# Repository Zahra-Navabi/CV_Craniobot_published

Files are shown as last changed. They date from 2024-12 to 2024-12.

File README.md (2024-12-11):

# CV-Craniobot

## Preprint
You can find the preprint of this work at:  
[https://www.biorxiv.org/content/10.1101/2024.09.03.611036v1](https://www.biorxiv.org/content/10.1101/2024.09.03.611036v1)

## Repository Structure
- **Robot_files**: Contains all robot software files.
- **CAD_files**: Contains all CAD files of the robot parts.
- **Other_files**: Other related files.

## Requirements
In addition to MATLAB and LabVIEW, the following software must be installed:  
- **Kinesis software** from Thorlabs  
  [Kinesis-LabVIEW Documentation](https://www.thorlabs.com/Software/Motion%20Control/Kinesis/Kinesis-labview.pdf)  
- **OCT system native software** (Lumedica OQ Stratoscope)  
- **Virtual Serial Port Driver**

## Usage
Ensure all dependencies are installed before running the software. Follow the provided documentation for setup and usage instructions.

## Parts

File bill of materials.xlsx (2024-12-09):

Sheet: Purchased equipments
OCT equipment | Part number | Count | Price for each | Link | Cost
OQ Stratascope 1.0 |  | 1 | 19995.00 | https://www.lumedicasystems.com/stratascope/ | 19995
Extended support for OQ Stratascope |  | 1 | 1895.00 |  | 1895
Workstation Package for OQ Stratascope |  | 1 | 595.00 |  | 595
Virtual Serial Port Virtual serial port |  | 1 | 295.00 |  | 295
Optomechanical parts (purchased)
Aluminum Breadboard 12" x 24" x 1/2", 1/4"-20 Taps | MB1224 | 1 | 302.56 | https://www.thorlabs.com/thorproduct.cfm?partnumber=MB1224 | 302.56
Right-Angle Mounting Plate, 1/4"-20 Compatible | AP90 | 2 | 94.74 | https://www.thorlabs.com/thorproduct.cfm?partnumber=AP90#ad-image-0 | 189.48
4-40 Stainless Steel Cap Screw, 3/8" Long, 50 Pack | SH4S038 | 1 | 9.5 | https://www.thorlabs.com/thorproduct.cfm?partnumber=SH4S038 | 9.5
Low-Profile T-Nut, 1/4"-20 Tapped Hole, 10 Pack | XE25T3 | 1 | 11.65 | https://www.thorlabs.com/thorproduct.cfm?partnumber=XE25T3 | 11.65
30°/60° Angled Mounting Plate, 1/4"-20 Compatible | AP30 | 1 | 147.91 | https://www.thorlabs.com/thorproduct.cfm?partnumber=AP30 | 147.91
50 mm x 75 mm Construction Rail, 20" Long, 1/4"-20 Taps | XE5075L20 | 2 | 89.28 | https://www.thorlabs.com/thorproduct.cfm?partnumber=XE5075L20 | 178.56
Right-Angle Clamp for Ø1/2" Posts, 3/16" Hex | RA90 | 3 | 10.82 | https://www.thorlabs.com/thorproduct.cfm?partnumber=RA90 | 32.46
Adapter Plate with 1/4"-20 and 8-32 Tapped Holes for MTS25 and MTS50 Stages | MTSA1 | 2 | 51.98 | https://www.thorlabs.com/thorproduct.cfm?partnumber=MTSA1 | 103.96
Ø1/2" Optical Post, SS, 8-32 Setscrew, 1/4"-20 Tap, L = 2" | TR2 | 6 | 5.9 | https://www.thorlabs.com/thorproduct.cfm?partnumber=TR2 | 35.4
3" Long Corner Bracket for Aluminum Bolt-Together Framing | 8681N11 | 8 | 13.96 | https://www.mcmaster.com/products/l-shaped-brackets/aluminum-bolt-together-framing-and-fittings/ | 111.68
Load-Rated Threaded Bumper | 93115K111 | 6 | 3 | https://www.mcmaster.com/93115K111/ | 18
motorized stages
50 mm (1.97") Motorized Translation Stage Bundled with Controller and Power Supply, 8-32 and 4-40 Taps | KMTS50E | 2 | 1856.26 | https://www.thorlabs.com/thorproduct.cfm?partnumber=KMTS50E#ad-image-0 | 3712.52
300 mm Translation Stage with Stepper Motor, Integrated Controller, M6 Taps | LTS300C | 1 | 3595.86 | https://www.thorlabs.com/thorproduct.cfm?partnumber=LTS300C | 3595.86
30 mm Motorized Linear Translation Stage, 1/4"-20 Tapped Holes | M30X - Kinesis | 1 | 2920.09 | https://www.thorlabs.com/thorproduct.cfm?partnumber=M30X | 2920.09
Other equipments: |  |  |  |  | 0
AMD Ryzen Series Video Editing Custom PC System * |  | 1 | 3023.83 |  | 3023.83
Miniature End Mills - Square - Stub & Standard, Miniature End Mills | 13908 | 1 | 35.2 | https://www.harveytool.com/products/tool-details-13908 | 35.2
Rampower Digital 45 Sets | RAMPOWER45SETC2 | 1 | 285 | https://www.ramprodinc.com/rampower-digital-45-sets/ | 285
MS100 Portable USB Microscope | TSMS100 | 1 | 39.99 | https://teslong.com/products/ms100-industrial | 39.99
Surge Protector Power Strip |  | 1 | 15.99 | https://www.amazon.com/Protector-Nuetsa-Extension-Outlets-Joules/dp/B09F2XPJ47?hvadid=697649766938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 | 15.99
Powered USB 3.0 Hub, Wenter 11-Port Hub Splitter |  | 1 | 38.99 | https://www.amazon.com/WENTER-Splitter-Individual-Switches-Charging/dp/B08YNPXPRW | 38.99
* Specs: AMD Ryzen Series Video Editing Custom PC System Computer Case: Corsair Carbide Series 4000D Black ATX Case Fan: 120mm Ball Bearing Case Fan Power Supply: Thermaltake Smart 600W 80 PLUS Bronze Power Supply Motherboard: GIGABYTE X570 AORUS ELITE WIFI AM4/ AMD X570/ DDR4/ PCIE 4.0/ SATA3&USB3.2/ M.2/ A&GbE/ WIFI / BLUETOOTH/ ATX Processor: AMD Ryzen 9 5950X AM4 3.4GHz 16-Core Processor CPU Cooling Fan: 120mm Quiet Edition Water / Liquid CPU Cooler Memory: 64GB DDR4 High Performance Memory M2 SSD: 2TB Intel M.2 2280 Internal SSD Hard Drive: 3TB Storage Drive SATA3/SATA 6.0 GB/s 64MB Video card: NVIDIA Quadro T600 4GB GDDR6 4Mini DisplayPorts PCI-Express Sound Card: High Definition Audio with High Quality Audio Capacitors (onboard) Controllers: 2x Port Serial PCI-x Card Network Card: 100/1000 Gigabit Network Card (onboard) Wireless Card: 300Mbps Wireless N PCI-x Adapter Card Reader: External 23 – In – 1 Universal Card Reader / Writer Monitor: 27" Samsung LED/LCD Monitor Keyboard: Logitech Wireless Desktop MK320 Keyboard and Mouse Speakers: Logitech Z150 2.0 Speaker System Operating System: MS Windows 10 Pro 64-bit Warranty: Assembled and tested, 3 years parts and 3 Year labor warranty

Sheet: Custom parts
Aluminum-machined parts |  | Count | Price
Bite bar* | Refer to the following paper:(https://doi.org/10.1038/s41596-020-0318-4) | 1
Ear bars* | Refer to the following paper:(https://doi.org/10.1038/s41596-020-0318-4) | 2
LTS300C to M30X - Kinesis connector* | Use the CAD file provided in the CAD folder | 1
KMTS50E to XE5075L20 connector* | Use the CAD file provided in the CAD folder | 2
Stereotax* | Use the CAD file provided in the CAD folder
3D printed:
OCT scanner holder | Use the CAD file provided in the CAD folder | 1
Electrical driller holder | Use the CAD file provided in the CAD folder | 1
Nose cone | Refer to the following paper:(https://doi.org/10.1038/s41596-020-0318-4) | 1
* All can be Machined from the following:
Oversized Multipurpose 6061 Aluminum Sheet | 18"X18" Sheet | 1 | 169.1 | https://www.mcmaster.com/89155K12/

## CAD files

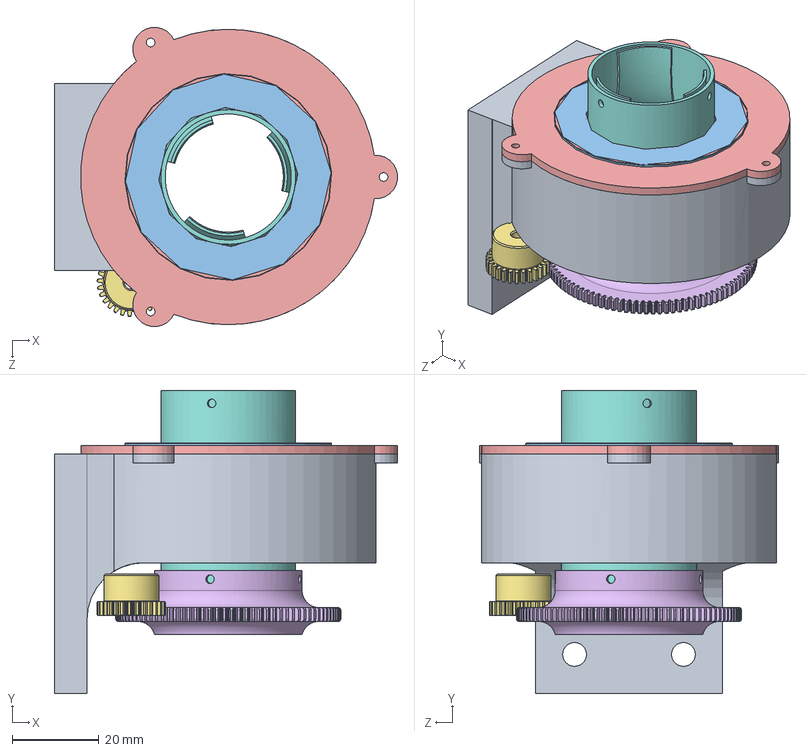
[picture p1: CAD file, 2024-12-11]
CAD_files/Assem2ndversion.SLDASM
79.0 x 69.8 x 68.8 mm
holder1
5709K85_TAPERED-ROLLER BEARING WITH STEEL RING
6655K240_PLASTIC THRUST BALL BEARING
6655K240_PLASTIC THRUST BALL BEARING - Copy
57655K310_PLASTIC GEAR--14-.5 DEG PRESSURE ANGLE
57655K170_PLASTIC GEAR--14-.5 DEG PRESSURE ANGLE
central holder_2 (1)

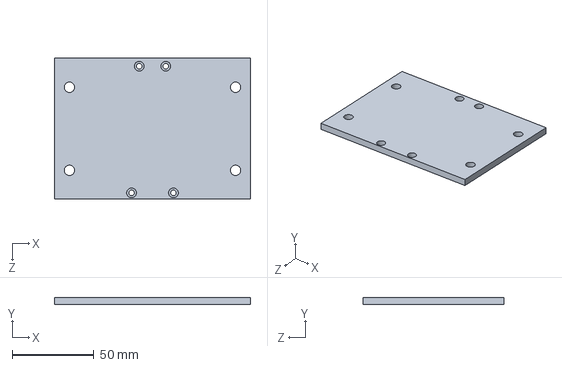
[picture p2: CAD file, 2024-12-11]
CAD_files/actuator connector2.SLDPRT
119.9 x 4.57 x 86.4 mm

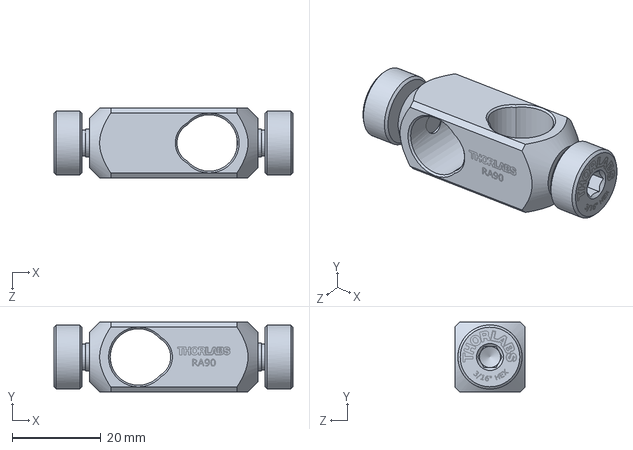
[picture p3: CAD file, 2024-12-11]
CAD_files/RA90-Solidworks.sldprt
54.0 x 15.7 x 15.7 mm

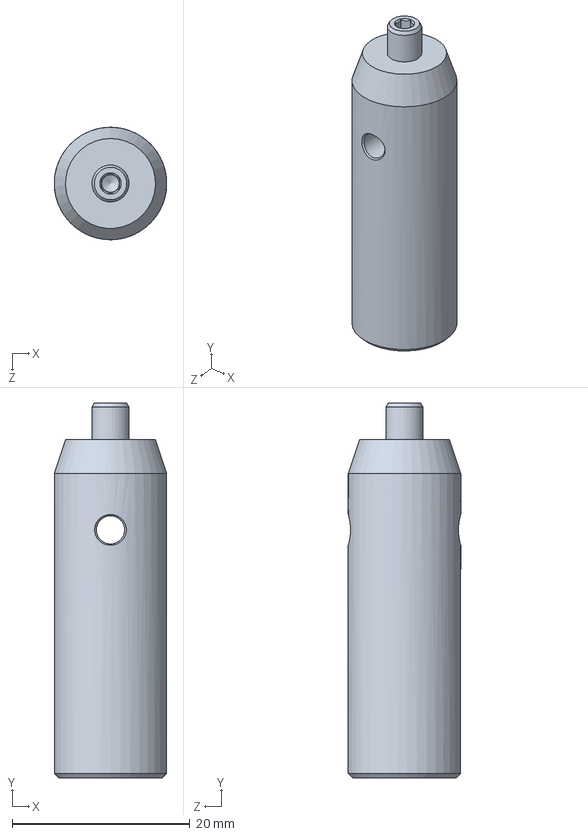
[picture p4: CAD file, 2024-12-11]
CAD_files/TR1.5-Solidworks (1).sldprt
12.7 x 42.2 x 12.7 mm

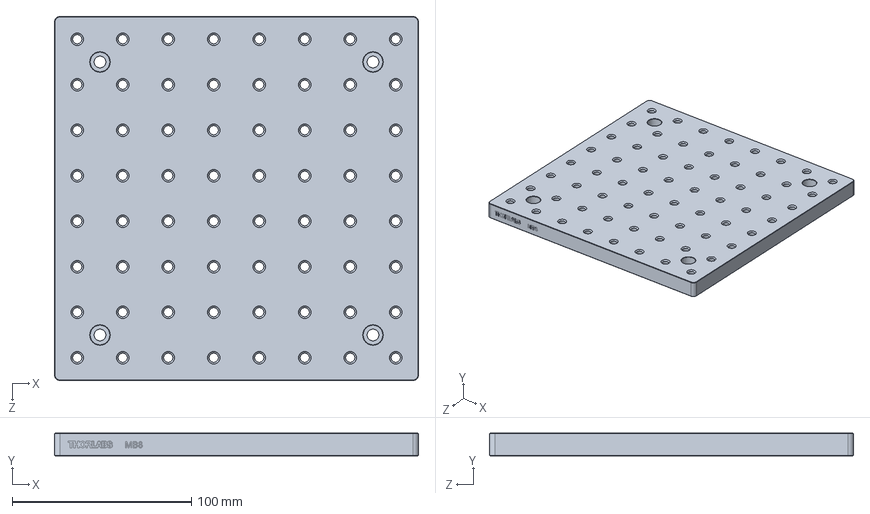
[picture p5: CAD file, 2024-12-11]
CAD_files/MB8-Solidworks.sldprt
203.2 x 12.7 x 203.2 mm

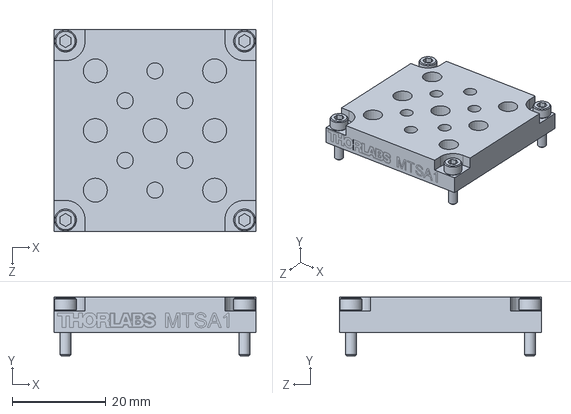
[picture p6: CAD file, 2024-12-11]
CAD_files/MTSA1-Solidworks.sldprt
43.0 x 12.5 x 43.0 mm

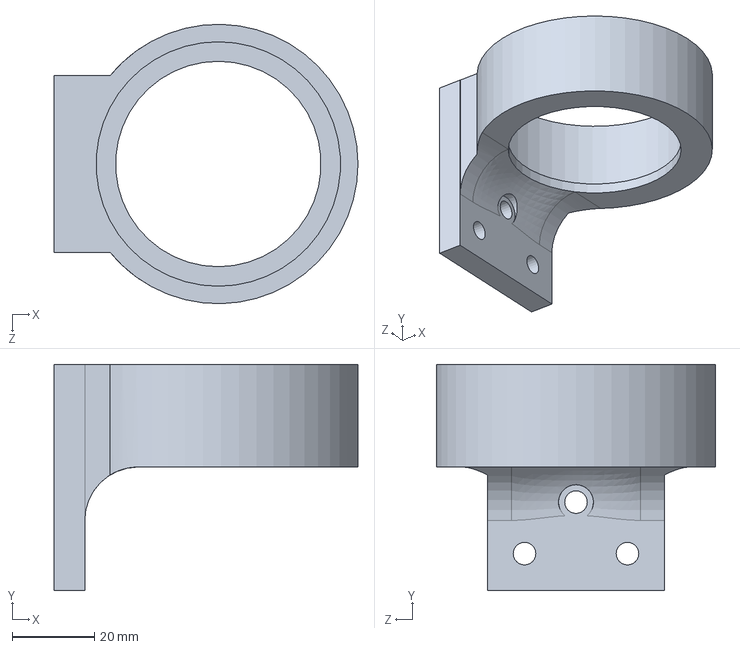
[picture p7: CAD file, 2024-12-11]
CAD_files/holder1.SLDPRT
74.0 x 55.1 x 68.0 mm

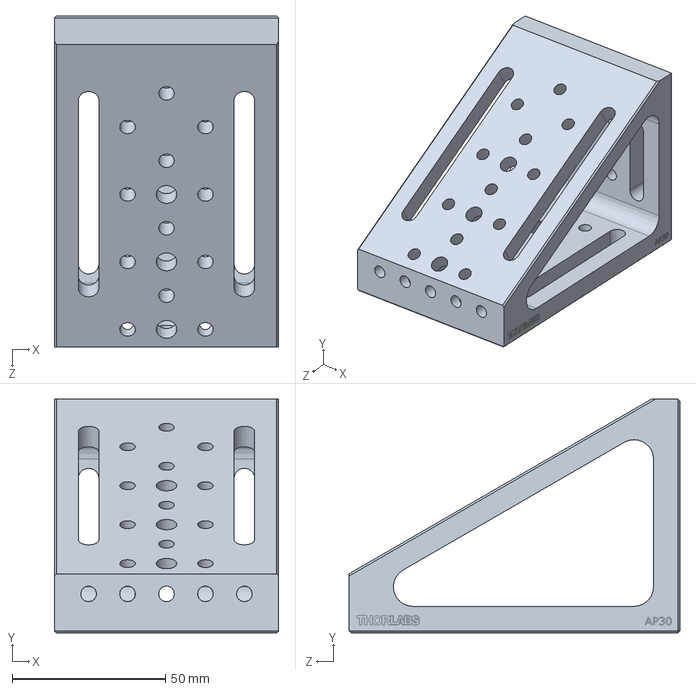
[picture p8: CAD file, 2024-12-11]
CAD_files/AP30-Solidworks.sldprt
73.2 x 76.2 x 107.9 mm

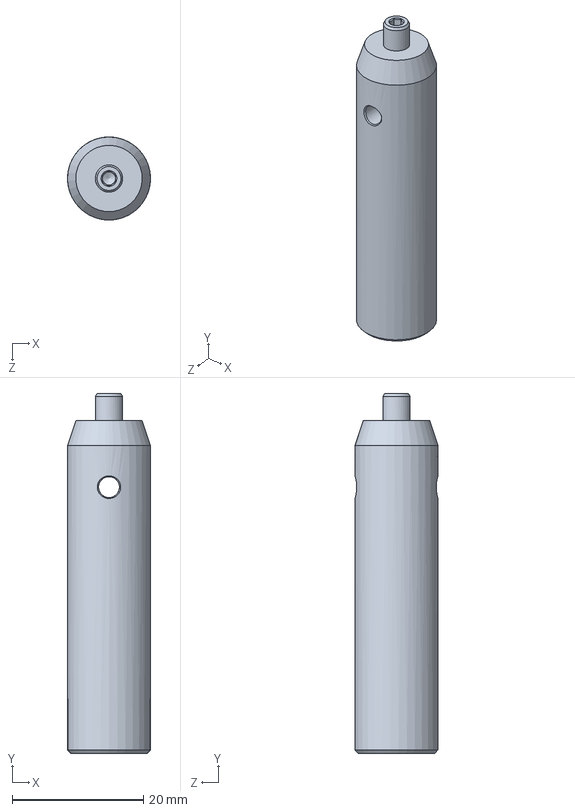
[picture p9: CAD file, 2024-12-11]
CAD_files/TR2-Solidworks.sldprt
12.7 x 54.9 x 12.7 mm

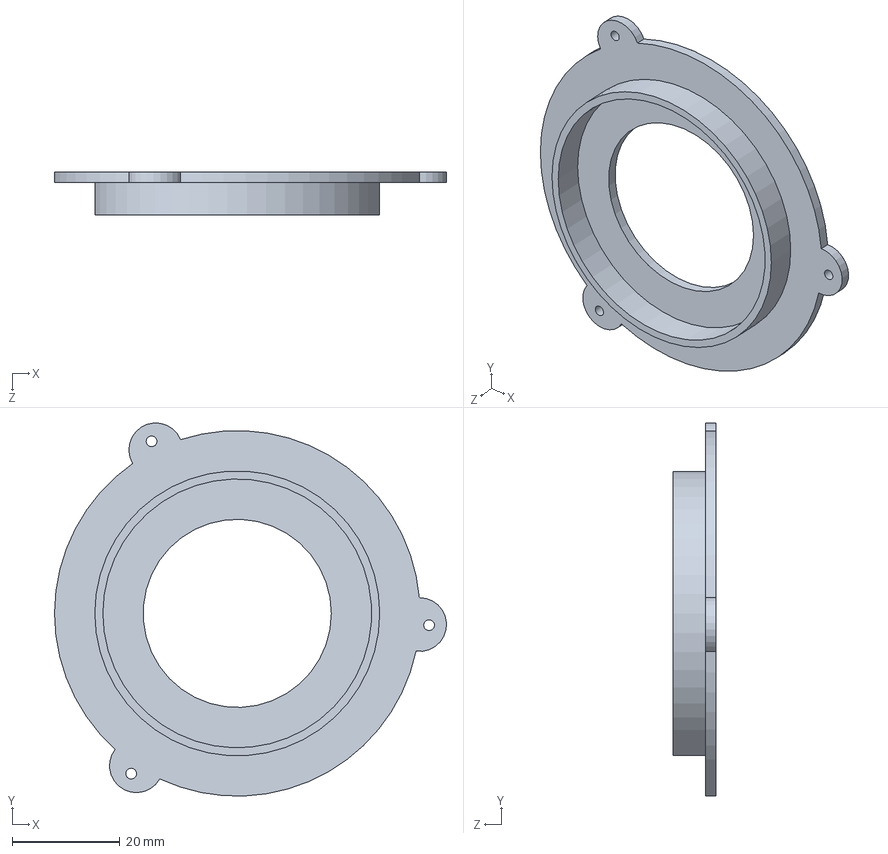
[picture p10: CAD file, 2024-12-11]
CAD_files/Part3.SLDPRT
72.9 x 69.4 x 8.00 mm

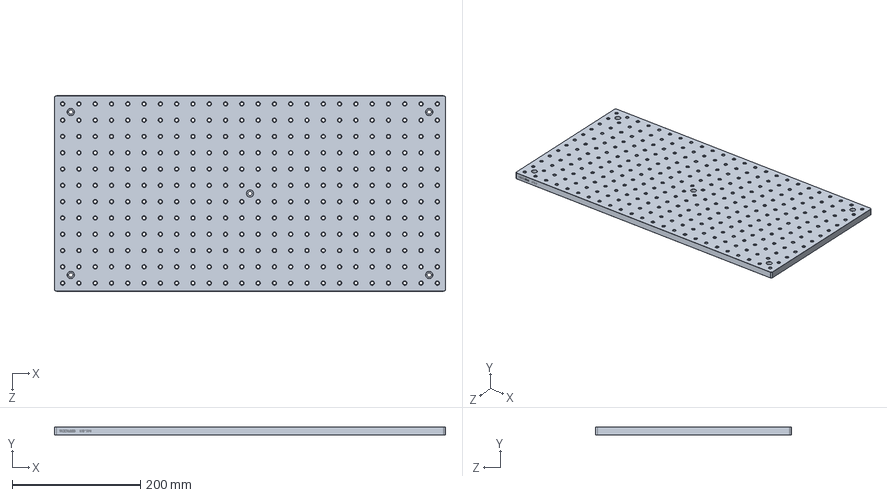
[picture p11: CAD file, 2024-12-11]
CAD_files/MB1224-Solidworks.sldprt
609.6 x 12.7 x 304.8 mm

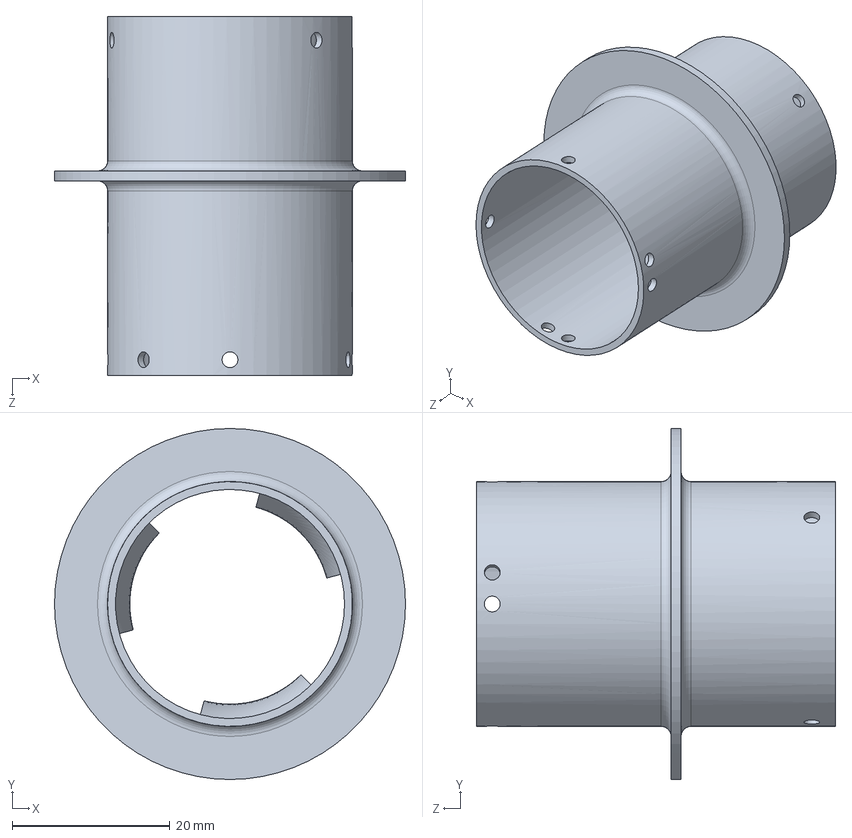
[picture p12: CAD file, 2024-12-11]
CAD_files/central holder_2 (1).SLDPRT
44.5 x 44.5 x 45.5 mm

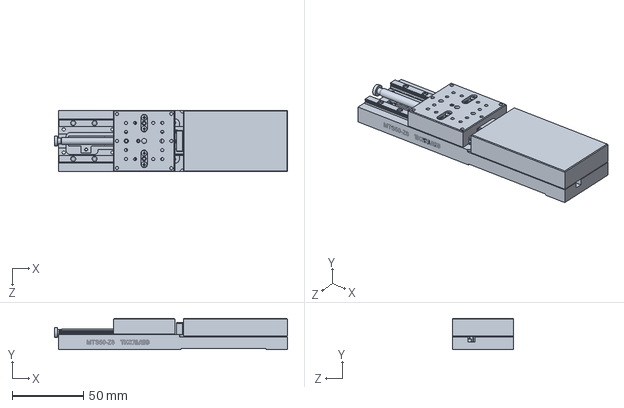
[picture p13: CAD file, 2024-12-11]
CAD_files/MTS50-Z8-Solidworks.SLDPRT
163.4 x 22.0 x 43.0 mm

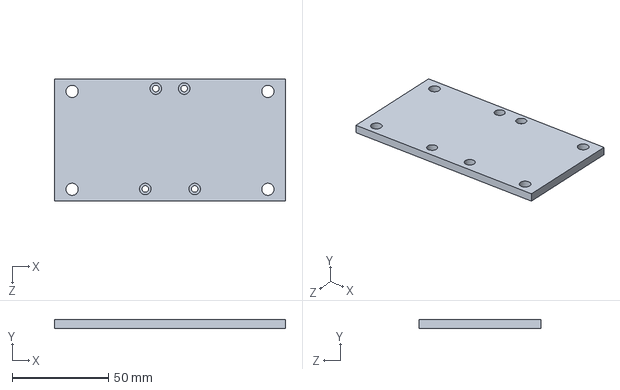
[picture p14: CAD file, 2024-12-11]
CAD_files/actuator connector.SLDPRT
119.9 x 4.57 x 63.5 mm

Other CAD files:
CAD_files/OCT camera.SLDPRT
CAD_files/XE75A90-Solidworks.sldprt
CAD_files/A-00001 - STD SCANNER.STEP
CAD_files/XE5075L20-Solidworks.sldprt
CAD_files/5709K85_TAPERED-ROLLER BEARING WITH STEEL RING.SLDPRT
CAD_files/57655K170_PLASTIC GEAR--14-.5 DEG PRESSURE ANGLE.SLDPRT
CAD_files/57655K310_PLASTIC GEAR--14-.5 DEG PRESSURE ANGLE.SLDPRT
CAD_files/6655K240_PLASTIC THRUST BALL BEARING - Copy.SLDPRT
CAD_files/6655K240_PLASTIC THRUST BALL BEARING.SLDPRT
CAD_files/A-00001 - STD SCANNER.SLDPRT
CAD_files/MB4A-Solidworks.sldprt
CAD_files/MTS25_M-Z8-Solidworks.sldprt

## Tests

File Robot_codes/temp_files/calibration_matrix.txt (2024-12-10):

-0.0115514509558118	0.000145536912427803	0.000178083572371866	-6.01020220041744e-13
7.48144980899778e-05	0.0122803958517203	0.000246024187261954	-7.94636757170704e-13
-0.00024657572867831	0.000291099357591857	-0.0145723685422898	-7.33944156280928e-13
20.4206793303697	5.65904985263947	41.3177311319089	0.999999999999437

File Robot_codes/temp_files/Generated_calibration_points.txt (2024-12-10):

19.630	17.972	16.315	19.596	18.000	16.372	19.572	17.916	16.407
9.800	10.000	10.273	11.342	11.600	11.800	13.000	13.113	13.461
38.078	36.237	37.430	36.722	36.400	36.149	37.139	37.716	38.159
1.000	1.000	1.000	1.000	1.000	1.000	1.000	1.000	1.000

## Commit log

2024-12-09 add bill of materials
    [bill of materials.xlsx]
2024-12-10 add files V2
    [gigapixel_3.csv, gigapixel_R_half.csv]
